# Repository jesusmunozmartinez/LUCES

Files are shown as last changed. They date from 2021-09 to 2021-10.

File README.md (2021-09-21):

# LUCES
## TFM LUCES Master SEEI
#### TITULACIÓN: Máster en Sistemas Electrónicos para Entornos Inteligentes
#### TÍTULO: "LUCES: Sistema inalámbrico de control de luminarias"
##### PALABRAS CLAVE: LUCES, ILUMINACIÓN, MESH, PCB, RED, SENSORES.
#### RESUMEN:
Este proyecto consiste en el desarrollo hardware, software y documentación de un sistema de control de iluminación inalámbrico. Este sistema permite integrar una luminaria convencional dentro de un sistema de control inteligente conectado a Internet. Su uso está orientado a la iluminación de espacios públicos como calles y parques. El control de encendido y de los niveles lumínicos de las luminarias integradas en el sistema, está basado en temporizaciones horarias, luminosidad ambiente o solar y presencia de usuarios en la vía iluminada. El sistema avisa por correo electrónico en caso de fallo de luminaria y proporciona información del consumo eléctrico, luminosidad ambiente, uso de la vía, etc. La arquitectura está basada en una red WiFi mallada con motas que controlan las luminarias y un nodo central que hace de puente con internet y proporciona el acceso a la gestión del sistema. La verificación de los requisitos se ha realizado sobre los prototipos funcionales desarrollados. Concluir que este sistema destaca por proporcionar la reducción del consumo eléctrico e inicia la posibilidad de integración de sistemas de iluminación en las “Ciudades inteligentes”. 

#### TITLE: “LIGHTS: Wireless luminaire control system”
##### KEYWORDS: LIGHTS, LIGHTING, MESH, PCB, NETWORK, SENSORS.
#### ABSTRACT:
This project consists of the development of hardware, software, and documentation of a wireless lighting control system. This system allows the integration of a conventional luminaire into an intelligent control system connected to the Internet. Its use is oriented to the lighting of public spaces such as streets and parks. The control of switching on and lighting levels of the luminaires integrated in the system is based on hourly timings, ambient or solar luminosity and the presence of users on the illuminated road. The system alerts by e-mail in case of luminaire failure and provides information on power consumption, ambient brightness, road use, etc. The architecture is based on a meshed WiFi network with motes that control the luminaires and a central node that bridges the Internet and provides access to system management. The verification of the requirements has been performed on the developed functional prototypes. To conclude that this system stands out for providing the reduction of electricity consumption and initiates the possibility of integration of lighting systems in "Smart Cities".

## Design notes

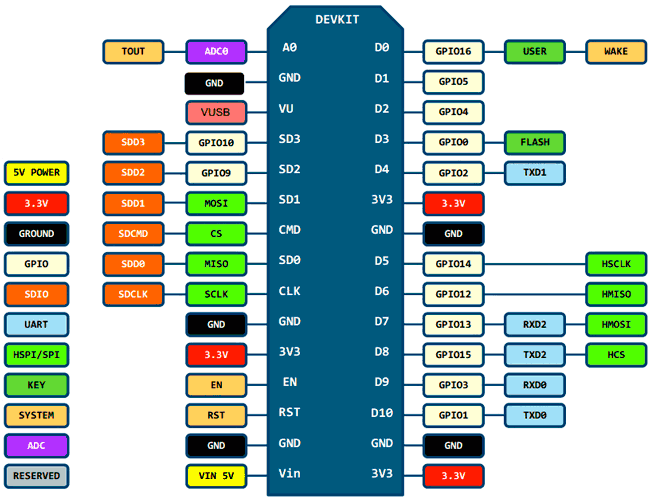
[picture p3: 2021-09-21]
Datasheet/esp8266-nodemcu-pinout-v3.png

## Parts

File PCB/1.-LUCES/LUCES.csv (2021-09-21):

Source: | C:\Users\kisum\Google Drive\UMA\MASTER_SEEI\16.-TFM\3.-Planos\kicad\LUCES\LUCES.sch
Date: | 01/08/2021 21:47:19
Tool: | Eeschema (5.1.10)-1
Component Count: | 5
Ref | Value | Footprint | Datasheet | Manufacturer | Vendor
J1 | Screw_Terminal_01x02 | TerminalBlock:TerminalBlock_Altech_AK300-2_P5.00mm | ~
PS1 | HLK-PM03 | Converter_ACDC:Converter_ACDC_HiLink_HLK-PMxx | http://www.hlktech.net/product_detail.php?ProId=59
R1 | 470 | Resistor_SMD:R_0805_2012Metric_Pad1.20x1.40mm_HandSolder | ~
SW1 | SW_Push | Button_Switch_SMD:SW_Push_1P1T_NO_6x6mm_H9.5mm | ~
U1 | ESP-12F | RF_Module:ESP-12E | http://wiki.ai-thinker.com/_media/esp8266/esp8266_series_modules_user_manual_v1.1.pdf

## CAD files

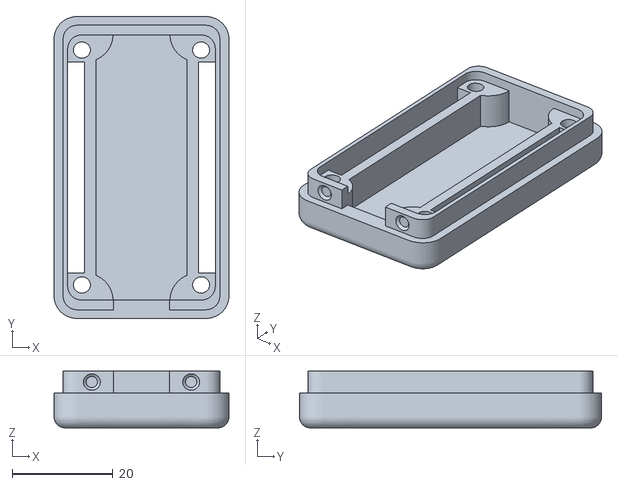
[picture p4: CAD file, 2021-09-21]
Carcasa3D/LucesNC-bottom.stl
34.8 x 60.1 x 11.3

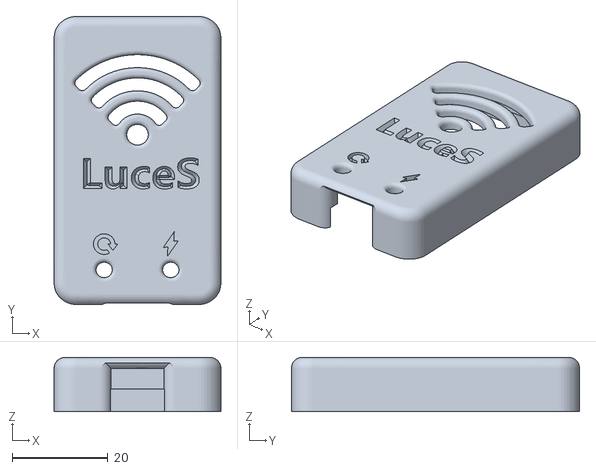
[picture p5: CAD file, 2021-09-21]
Carcasa3D/LucesNC-Top.stl
34.8 x 60.1 x 11.3

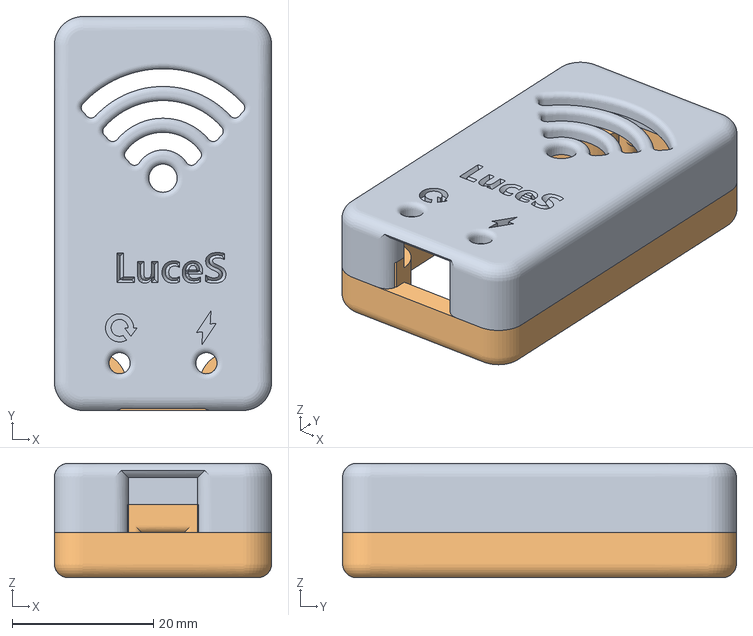
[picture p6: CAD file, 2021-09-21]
Carcasa3D/Luces.3mf
30.8 x 55.8 x 16.2 mm

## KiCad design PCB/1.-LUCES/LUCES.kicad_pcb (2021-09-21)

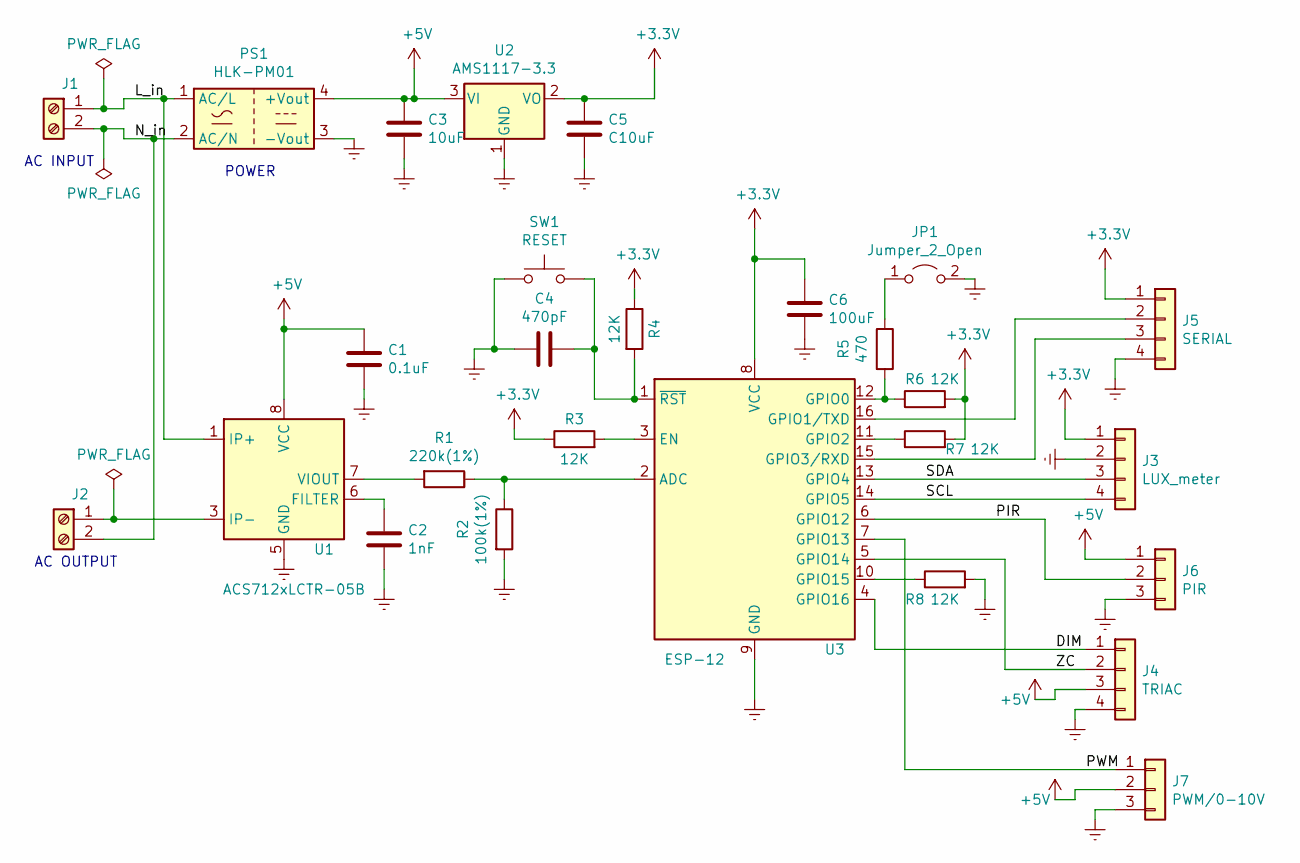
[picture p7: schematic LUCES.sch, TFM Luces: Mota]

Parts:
C1: 0.1uF; C_0805_2012Metric
C2: 1nF; C_0805_2012Metric
C3: 10uF; C_1206_3216Metric
C4: 470pF; C_0805_2012Metric
C5: C10uF; C_1206_3216Metric
C6: 100uF; C_0805_2012Metric
J1, J2: Screw_Terminal_01x02; TerminalBlock_Phoenix_MKDS-1,5-2_1x02_P5.00mm_Horizontal
J3: LUX_meter; JST_XH_S4B-XH-A-1_1x04_P2.50mm_Horizontal
J4: TRIAC; PinHeader_1x04_P2.54mm_Vertical
J5: SERIAL; PinHeader_1x04_P2.54mm_Vertical
J6: PIR; JST_XH_S3B-XH-A-1_1x03_P2.50mm_Horizontal
J7: PWM/0-10V; PinHeader_1x03_P2.54mm_Vertical
JP1: Jumper_2_Open; PinHeader_1x02_P2.54mm_Vertical
PS1: HLK-PM01; Converter_ACDC_HiLink_HLK-PMxx
R1: 220k(1%); R_0805_2012Metric_Pad1.20x1.40mm_HandSolder
R2: 100k(1%); R_0805_2012Metric_Pad1.20x1.40mm_HandSolder
R3, R4, R6, R7, R8: 12K; R_0805_2012Metric_Pad1.20x1.40mm_HandSolder
R5: 470; R_0805_2012Metric_Pad1.20x1.40mm_HandSolder
SW1: RESET; SW_SPST_PTS645
U1: ACS712xLCTR-05B; SOIC-8_3.9x4.9mm_P1.27mm
U2: AMS1117-3.3; SOT-223-3_TabPin2
U3: ESP-12

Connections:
+3V3: C5.1, C6.1, J3.1, J5.1, R3.1, R4.1, R6.2, R7.2, U2.2 (VO), U3.8 (VCC)
+5V: C1.1, C3.1, J4.3, J6.1, J7.2, PS1.4 (+Vout), U1.8 (VCC), U2.3 (VI)
/DIM: J4.1, U3.4 (GPIO16)
/L_in: J1.1, PS1.1 (AC/L), U1.1 (IP+), U1.2 (IP+)
/N_in: J1.2, J2.2, PS1.2 (AC/N)
/PIR: J6.2, U3.6 (GPIO12)
/PWM: J7.1, U3.7 (GPIO13)
/SCL: J3.4, U3.14 (GPIO5)
/SDA: J3.3, U3.13 (GPIO4)
/ZC: J4.2, U3.5 (GPIO14)
Earth: C1.2, C2.2, C3.2, C4.2, C5.2, C6.2, J3.2, J4.4, J5.4, J6.3, J7.3, JP1.2 (B), PS1.3 (-Vout), R2.2, R8.2, SW1.1, U1.5 (GND), U2.1 (GND), U3.9 (GND)
unnamed: C2.1, U1.6 (FILTER)
unnamed: C4.1, R4.2, SW1.2, U3.1 (~RST)
unnamed: J2.1, U1.3 (IP-), U1.4 (IP-)
unnamed: J5.2, U3.16 (GPIO1/TXD)
unnamed: J5.3, U3.15 (GPIO3/RXD)
unnamed: JP1.1 (A), R5.1
unnamed: R1.1, R2.1, U3.2 (ADC)
unnamed: R1.2, U1.7 (VIOUT)
unnamed: R3.2, U3.3 (EN)
unnamed: R5.2, R6.1, U3.12 (GPIO0)
unnamed: R7.1, U3.11 (GPIO2)
unnamed: R8.1, U3.10 (GPIO15)

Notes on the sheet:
POWER
AC INPUT
AC OUTPUT

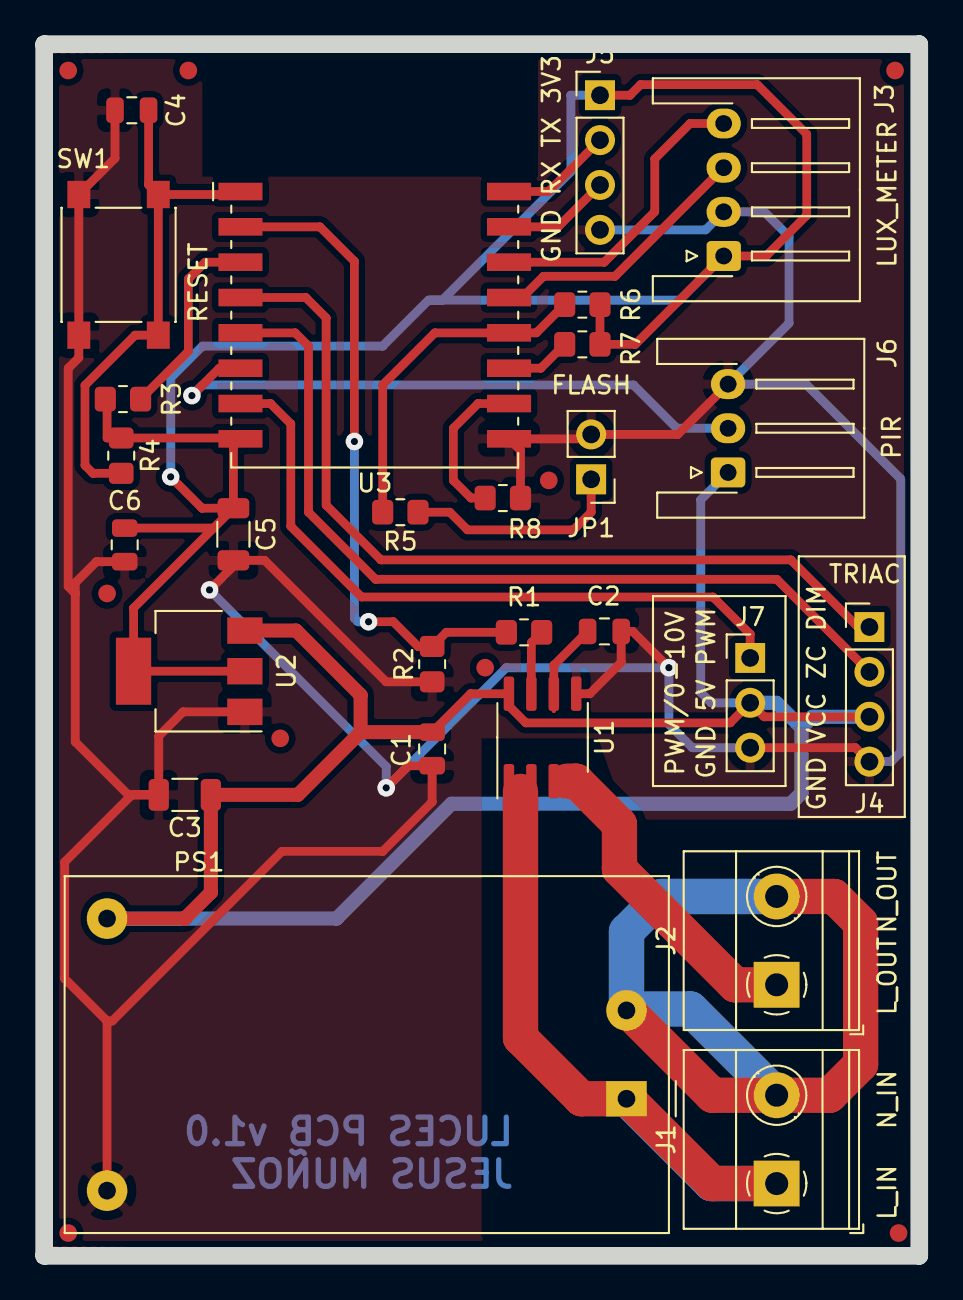
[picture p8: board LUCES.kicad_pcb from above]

Board: 2 copper layers, 49.5 x 68.6 mm, 27 parts (0 on the bottom side), 23 nets.

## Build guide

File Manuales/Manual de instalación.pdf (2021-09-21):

LUCES. Sistema inalámbrico de control de luminaria | Manual de instalación

# Manual de instalación V1.0

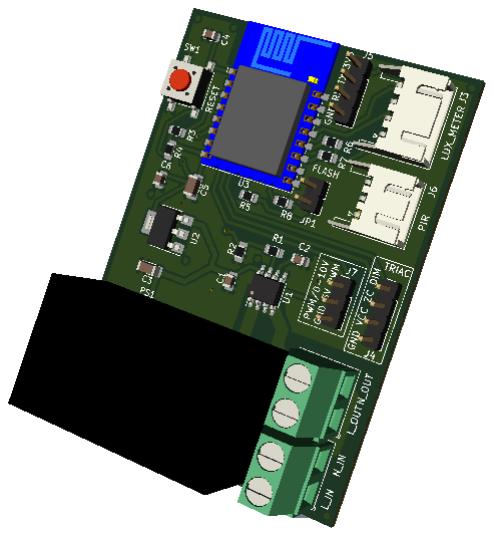
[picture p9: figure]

# Sistema inalámbrico de control de luminaria

# Especificaciones

Modelo | LUCES
Entrada | 100-240V AC 50/60Hz
Salida | 100-240V AC 50/60Hz 5A máxima
Carga máxima | 1200W/5A/
Wi-Fi | IEEE 802.11 b/g/n 2.4GHz
Sistemas operativos | Android/iOS/Windows/Linux/MacOS
Módulos de control de luminaria | 3 (uno por cada mota)
máximo número de motas | >50
Temperatura de funcionamiento | -10℃~40℃
Dimensiones | 70x50x34mm

# Introducción al producto

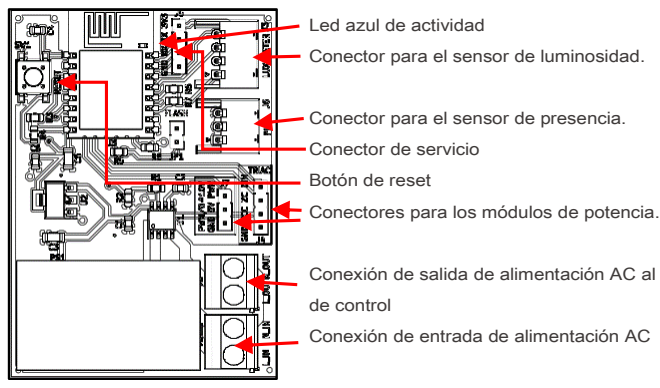
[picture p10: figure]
Led azul de actividad; Conector para el sensor de luminosidad.; Conector para el sensor de presencia.; Conector de servicio; Botón de reset; de control; Conexión de entrada de alimentación AC

Conectores para los módulos de potencia.

Conexión de salida de alimentación AC al módulo

¡Atención! Tenga cuidado de asegurarse que ha desconectado los cables de

alimentación AC antes de conectarlos.

# Características

Este sistema de control de luminaria está baso en un control integrado en un Nodo Central, accesible al usuario, y en un conjunto de motas inalámbricas instaladas por un profesional cualificado. Es por ello, que este manual, orientado al instalador, se centra en las motas inalámbricas.

Para una descripción del funcionamiento detallado del nodo central, consulte el manual del usuario.

El dispositivo es un controlador de luminarias inteligente mediante el protocolo Wi-Fi. Las motas inalámbricas integradas en las luminarias permiten un control de intensidad lumínica, detectar la luminosidad solar, consumo, presencia de personas, etc. , de tal forma que permite apagar o encender las luminarias de manera remota, programar el encendido o apagado en función de la luminosidad, solar o temporizado.

Control remoto

desde cualquier

plataforma

Programación
temporizada

Control
compartido

Monitoreo de
Alimentación

Estado de
sincronización

# Conexión de los sensores

Sensor de luminosidad.

El sensor de luminosidad se presenta con el siguiente aspecto, el color del soporte

puede diferir.

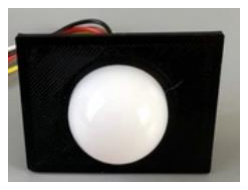
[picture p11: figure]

Elija una buena ubicación del sensor de luminosidad donde su medida no se vea afectada por la luz que emite la luminaria. Busque una zona de sombra de la luz de la luminaria como puede ser la parte superior o detrás del poste. La siguiente imagen muestra posibles ubicaciones recomendables.

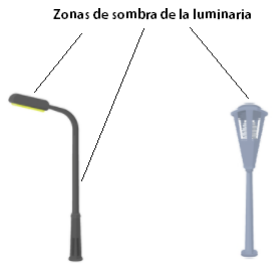
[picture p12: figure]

Una vez ubicado el sensor, conéctelo en el socket etiquetado como LUXMETER:

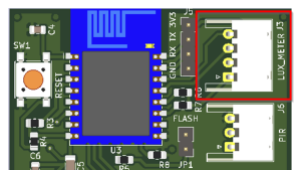
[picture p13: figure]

El sensor de luminosidad no necesita ningún tipo de ajuste ni calibración.

### Sensor de presencia de uso de la vía

El sensor de presencia de uso de la vía (PIR) se presenta con el siguiente aspecto, el

color del soporte puede diferir.

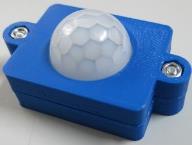
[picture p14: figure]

Antes de instalar él módulo puede ajustar los siguientes parámetros usando los potenciómetros que posee el módulo:

- Tiempo que permanece activo la señal de detección, desde 3 segundos hasta 5 minutos
- Distancia máxima de detección, desde 3 metras hasta 7 metros.

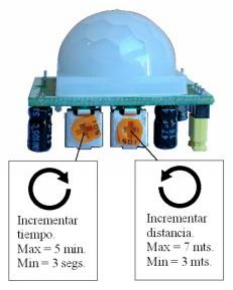
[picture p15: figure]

Elija una buena ubicación del sensor de presencia basándose que su rango de detección tiene un alcance de hasta 7 metros y ángulo de 110º. La siguiente imagen muestra posibles ubicaciones recomendables.

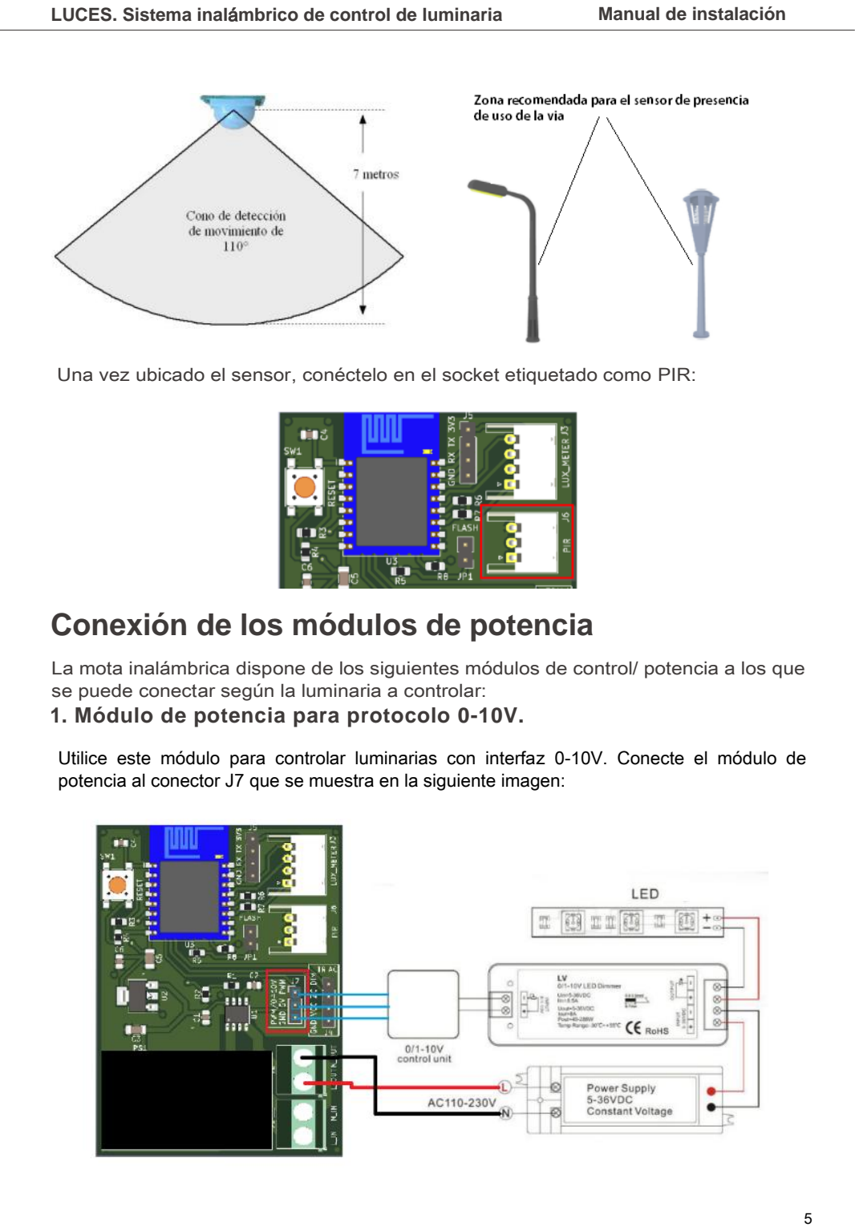
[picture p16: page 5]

Una vez ubicado el sensor, conéctelo en el socket etiquetado como PIR:

# Conexión de los módulos de potencia

La mota inalámbrica dispone de los siguientes módulos de control/ potencia a los que se puede conectar según la luminaria a controlar:
1. Módulo de potencia para protocolo 0-10V.

Utilice este módulo para controlar luminarias con interfaz 0-10V. Conecte el módulo de potencia al conector J7 que se muestra en la siguiente imagen:

2. Módulo de potencia para tensiones DC.

Utilice este módulo para controlar luminarias basadas en regulación de intensidad por ajuste de la tensión DC. Conecte el módulo de potencia al conector J7 que se muestra en la siguiente imagen:

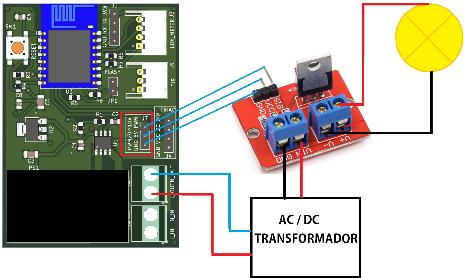
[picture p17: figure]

3. Módulo de potencia para corriente DC.

Utilice este módulo para controlar luminarias basadas en regulación de la intensidad por limitación de la corriente DC. Conecte el módulo de potencia al conector J7 que se muestra en la siguiente imagen:

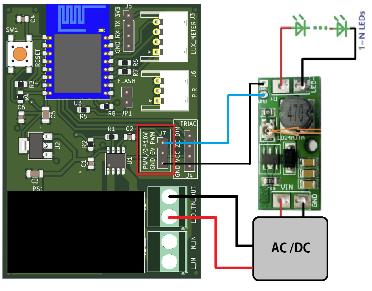
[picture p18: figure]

4. Módulo de potencia para tensiones AC.

Utilice este módulo para controlar luminarias que funcionen con corriente AC (100-240V) y tengan capacidad de regulación de luminosidad como las bombillas incandescentes. Las bombillas LED deben ser regulables, en caso contrario apreciará un parpadeo en las mismas. Conecte el módulo de potencia al conector J4.

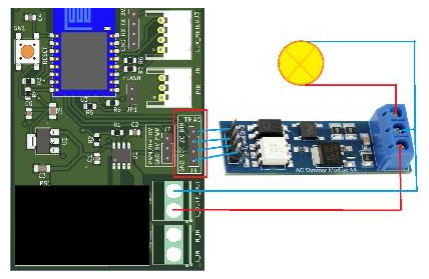
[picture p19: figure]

# Conexión de la alimentación AC

Una Realice la conexión de la alimentación AC siguiendo el siguiente esquema:

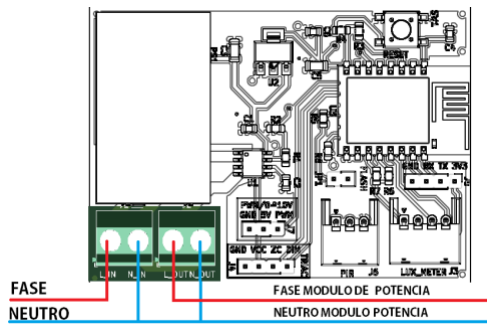
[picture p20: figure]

# Puesta en marcha

Revise que ha realizado todas las conexiones que a continuación se detallan:

1. Sensor de luminosidad ambiente y de presencia
2. Módulo de potencia, cableado de control y de alimentación
3. Alimentación AC de la mota inalámbrica.

Si todo está correctamente conectado puede alimentar la Mota inalámbrica, el led azul mostrará actividad y se conectará al nodo central.

Led azul de actividad

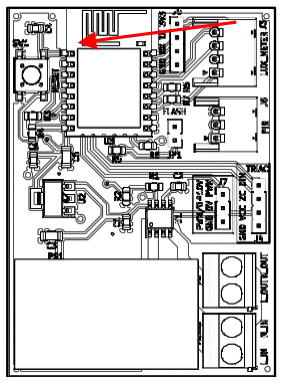
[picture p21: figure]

Si necesitas configurar el nodo central, presiona sin soltar el botón de acceso al modo configuración, luego el dispositivo entra en el modo de configuración donde podrás configurarlo conectándose al punto de acceso creado.

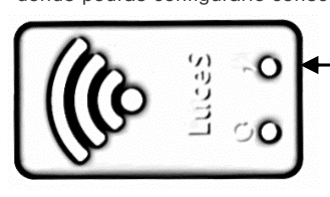
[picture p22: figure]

Botón de acceso al Modo de configuración

# Problemas frecuentes

P: ¿Por qué el dispositivo no se conecta a la red Wi-Fi MESH de mi instalación?
R: El dispositivo recién añadido necesita hasta 1 a 2 minutos para conectarse a la red Wi-Fi MESH. Si permanece sin conexión durante mucho tiempo, pulse el botón de reset. Si no ha solucionado el problema verifique los siguientes puntos

① Es posible que el Nodo central esté apagado. Verifique su funcionamiento

② Es posible que el dispositivo no tenga alimentación AC. Verifique si hay actividad en

el led azul.
③ Revise las conexiones con el módulo de potencia instalado.

P: ¿Por qué el dispositivo no detecta la presencia de usuarios en la vía correctamente”? R: El dispositivo de detección de personas (PIR) debe calibrarse correctamente según la zona a controlar, revise la sección “conexión de los sensores” para más información. Si no ha solucionado el problema verifique los siguientes puntos

① Es posible que el dispositivo de detección PIR no tenga alimentación. Verifique si

hay actividad en el del mismo.
② Revise las conexiones y el cableado con el módulo PIR.

P: ¿Por qué el dispositivo no detecta correctamente la luminosidad ambiente?
R: El dispositivo de detección de personas (PIR) debe calibrarse correctamente según la zona a controlar, revise la sección “conexión de los sensores” para más información. Si no ha solucionado el problema verifique los siguientes puntos

① Es posible que el dispositivo de detección PIR no tenga alimentación. Verifique si

hay actividad en el del mismo.
② Revise las conexiones y el cableado con el módulo PIR.

# FCC Warning

Changes or modifications not expressly approved by the party responsible for compliance could avoid the user’s authority to operate the equipment.
This device complies with part 15 of the FCC Rules. Operation is subject to the following two conditions: (1) This device may not cause harmful interference, and (2) this device must accept any interference received, including interference that may cause undesired operation.

FCC Radiation Exposure Statement:

This equipment complies with FCC radiation exposure limits set forth for an uncontrolled environment. This equipment should be installed and operated with minimum distance20cm between the radiator & your body. This transmitter must not be co-located or operating in conjunction with any other antenna or transmitter.

Note:

This equipment has been tested and found to comply with the limits for a Class B digital device, pursuant to part 15 of the FCC Rules. These limits are designed to provide reasonable protection against harmful interference in a residential installation. This equipment generates, uses and can radiate radio frequency energy and, if not installed and used in accordance with the instructions, may cause harmful interference to radio communications. However, there is no guarantee that interference will not occur in a particular installation. If this equipment does cause harmful interference to radio or television reception, which can be determined by turning the equipment off and on, the user is encouraged to try to correct the interference by one or more of the following measures:

— Reorient or relocate the receiving antenna.
— Increase the separation between the equipment and receiver.
— Connect the equipment into an outlet on a circuit different from that to which the receiver is connected.
— Consult the dealer or an experienced radio/TV technician for help.

# For FCC:

Frequency range
Wi-Fi: 2412-2462MHz | BT: 2402-2480MHz
Maximum RF output power of the product
Wi-Fi: 17.85dBm | BT: -1.90dBm

# For CE RED:

Frequency range
Wi-Fi: 2412-2472MHz | BT: 2402-2480MHz

Maximum RF output power of the product

Wi-Fi: 18.36dBm | BT: 3.93dBm (Inclusion antenna gain)

# RF exposure

RF exposure information: The Maximum Permissible Exposure ( MPE) level is calculated based on a distance of d=20 cm between the device and the human body. To maintain compliance with the RF exposure requirement, a separation distance of 20 cm between the device and the human should be maintained.

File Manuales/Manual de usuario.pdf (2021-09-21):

LUCES. Sistema inalámbrico de control de luminaria | Manual de usuario

# Manual de usuario V1.0

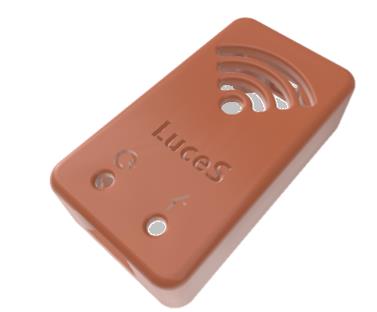
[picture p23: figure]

# Sistema inalámbrico de control de luminaria

# Especificaciones

Modelo | LUCES
Entrada | 100-240V AC 50/60Hz
Salida | 100-240V AC 50/60Hz 5A máxima
Carga máxima | 1200W/5A/
Wi-Fi | IEEE 802.11 b/g/n 2.4GHz
Sistemas operativos | Android/iOS/Windows/Linux/MacOS
Módulos de control de luminaria | 3 (uno por cada mota)
máximo número de motas | >50
Temperatura de funcionamiento | -10℃~40℃
Dimensiones | 70x50x34mm

# Introducción al producto

Botón de acceso al Modo de configuración

Botón de reset

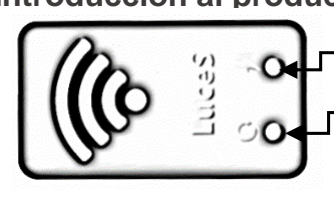
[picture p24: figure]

Nodo central

Para el nodo central se recomienda usar el adaptador de corriente de 1A suministrado.

# Características

Este sistema de control de luminaria está baso en un control integrado en un Nodo Central, accesible al usuario, y en un conjunto de motas inalámbricas instaladas por un profesional cualificado. Es por ello, que este manual, orientado al usuario, se centra en el uso del Nodo Central.

Para descripción del funcionamiento detallado de las motas inalámbricas, consulte el manual de instalación.

El dispositivo es un controlador de luminarias inteligente mediante el protocolo Wi-Fi. Las motas inalámbricas integradas en las luminarias permiten un control de intensidad lumínica, detectar la luminosidad solar, consumo, presencia de personas, etc. , de tal forma que permite apagar o encender las luminarias de manera remota, programar el encendido o apagado en función de la luminosidad, solar o temporizado.

Control remoto

desde cualquier

plataforma

Programación
temporizada

Control
compartido

Monitoreo de
Alimentación

Estado de
sincronización

# Primer encendido

Después de encender el nodo central por primera vez, el dispositivo se pondrá en modo de configuración durante el primer uso.

Si el dispositivo no entra en modo de configuración, podrá acceder a dicho modo mediante el botón de acceso en el panel de control o mediante la pulsación del botón Modo de configuración durante un segundo. A continuación, suelte el botón.

# Modo de configuración

Después de encender el nodo central por primera vez, el dispositivo se pondrá en modo de configuración durante el primer uso.

Para acceder al dispositivo, conéctese a la red WiFi con el nombre LUCES_CONFIG.

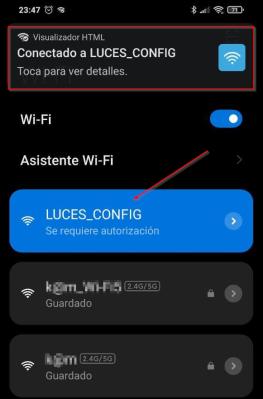
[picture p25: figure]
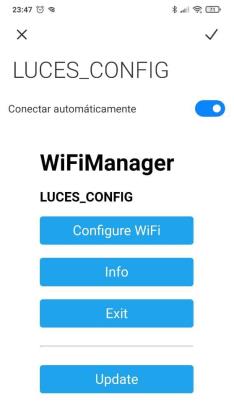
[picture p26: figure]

Una vez conectado a la red LUCES_CONFIG, podrá acceder directamente al panel de configuración abriendo su navegador o pulsando en su teléfono en “Toca para ver detalles”.
En caso de que esto no ocurra puede acceder manualmente en la dirección http://192.168.4.1.

### Añadir red local

Una vez dentro del panel de configuración, puse sobre el botón “Configure WiFi” para iniciar el escaneo de redes inalámbricas . Tras unos instantes aparecerá el listado con las redes encontradas.

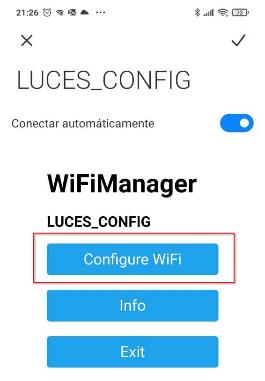
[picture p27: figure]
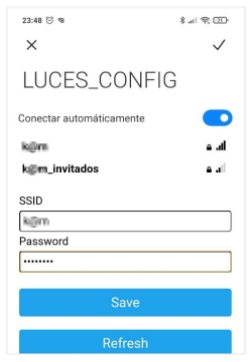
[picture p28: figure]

Seleccione la red, introduzca la contraseña de acceso y el Nodo Central se conectará a la red indicada con asignación dinámica de dirección IP. Realice una búsqueda en su red con el hostname “LUCES” o verifique en la tabla DHCP de su router la dirección IP asignada.

Recomendamos configurar una IP fija en su router para mayor comodidad. Consulte a su administrador de red para más información.

# Panel de control

Una vez conectado el Nodo Central a su red local con salida a internet, se sincronizará automáticamente la hora del sistema LUCES. Acceda al panel de control donde podrá realizar las siguientes funciones:
1. Información de la red de motas inalámbricas.

En el panel de control se muestran en tiempo real la información de las motas conectadas, su estado, las medidas de sus sensores y si se ha detectado fallo en la luminaria.

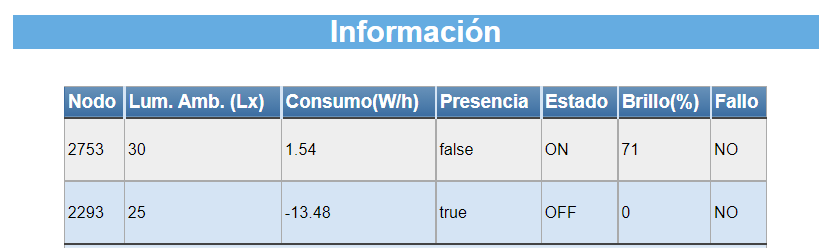
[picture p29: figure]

### 2. Configuración y control

Aquí podrá configurar el sistema de iluminación entre sus tres modos de encendido y sus tres modos de ajuste de intensidad lumínica. El ajuste de intensidad lumínica por detección de presencia está activado por defecto en todas las configuraciones, para intentar maximizar el ahorro de energía.

Modo Manual:

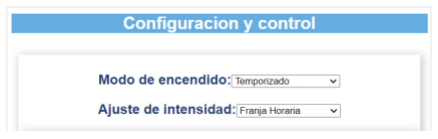
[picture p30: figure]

Este modo permite encender y apagar las luminarias en cualquier momento. Permite ajustar la intensidad lumínica y también la intensidad cuando no se detecten personas en las zonas donde se han instalado las luminarias.

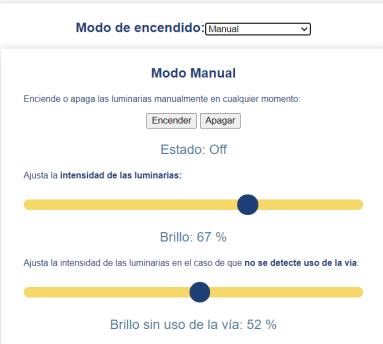
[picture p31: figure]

Modo de encendido por luminosidad ambiente:
Este modo permite encender y apagar las luminarias según el nivel lumínico configurado. Las luminarias se encenderán cuando el nivel de luminosidad medido se inferior al valor ajustado. Las luminarias se apagarán cuando el nivel lumínico se superior al ajustado.

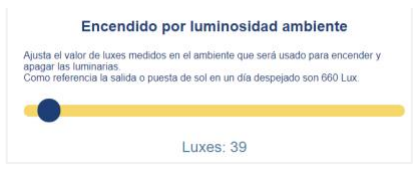
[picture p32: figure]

Luego, este modo dispone permite configurar manualmente la intensidad lumínica o mediante una selección por franja horaria, pensado para poner diferentes ajustes de luminosidad para el anochecer, noche y amanecer.

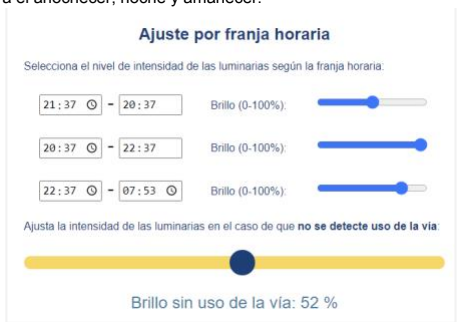
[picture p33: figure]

Modo de encendido temporizado:
En este modo el encendido y el apagado se realiza según las horas programadas. Los modos de ajuste de intensidad lumínica disponibles en este modo son todos los disponibles, así que podremos configurarlo tanto manualmente como por franja horaria y siempre con el modo de detección de uso de la vía funcionando.

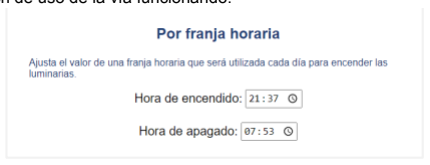
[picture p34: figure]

### 3. Añadir cuenta de correo de mantenimiento

El sistema permite configurar una cuenta de correo donde se avisará en caso de fallo de luminaria.

### 4. Registro del sistema

En esta sección podrá visualizar los eventos y mensajes registrados en el sistema de control Luces. Podrá descargar el fichero así borrarlo y /o recargar el visualizador para ver los últimos eventos registrados.

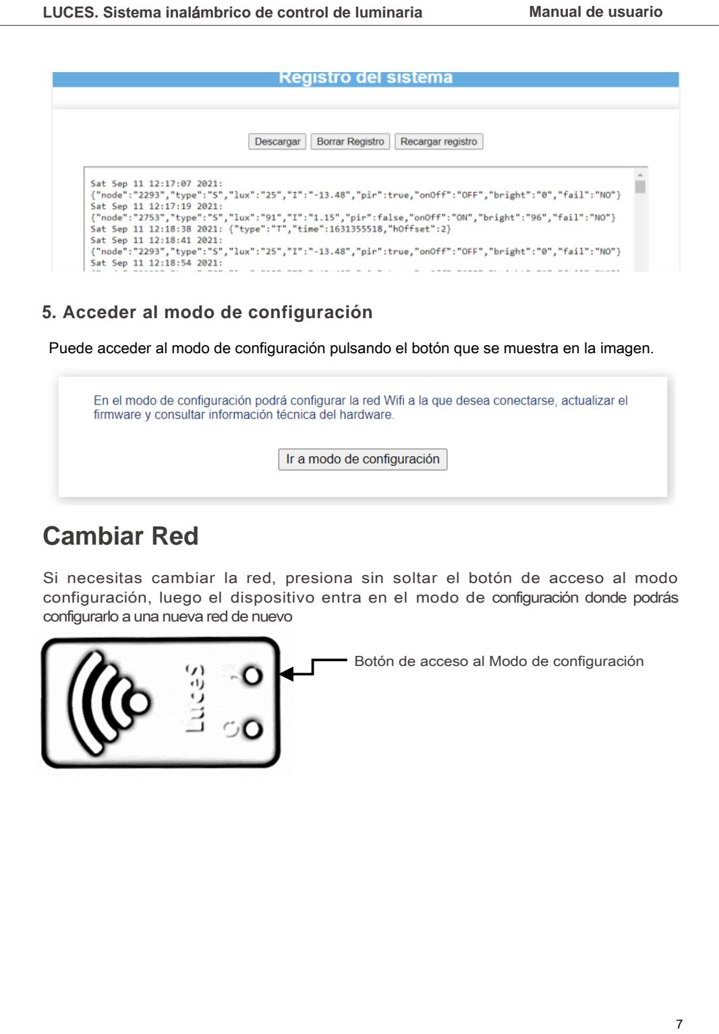
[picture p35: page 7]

### 5. Acceder al modo de configuración

Puede acceder al modo de configuración pulsando el botón que se muestra en la imagen.

# Cambiar Red

Si necesitas cambiar la red, presiona sin soltar el botón de acceso al modo configuración, luego el dispositivo entra en el modo de configuración donde podrás configurarlo a una nueva red de nuevo

Botón de acceso al Modo de configuración

# Problemas frecuentes

P: ¿Por qué el dispositivo no se conecta a la red Wi-Fi de mi instalación”?
R: El dispositivo recién añadido necesita de 1 a 2 minutos para conectarse a Wi-Fi y a la red. Si permanece sin conexión durante mucho tiempo, evalúe la situación analizando los siguientes puntos.

① Es posible que haya introducido una contraseña de Wi-Fi incorrecta.
② Es posible que la distancia entre el interruptor y el router sea demasiado grande o que el entorno provoque interferencias. Piense en acercarlos entre sí.
Si falla, vuelva a añadirlo.
③ La red 5G Wi-Fi no es compatible y solo admite la red inalámbrica de 2,4 GHz.
④ Es posible que el filtrado de direcciones MAC esté activado. Desactívelo.

Si no ha sido posible solucionar el problema mediante ninguno de los métodos anteriores, puede abrir la red de datos móviles del teléfono para crear un punto de acceso Wi-Fi y, a continuación, volver a añadir el dispositivo.

# FCC Warning

Changes or modifications not expressly approved by the party responsible for compliance could avoid the user’s authority to operate the equipment.
This device complies with part 15 of the FCC Rules. Operation is subject to the following two conditions: (1) This device may not cause harmful interference, and (2) this device must accept any interference received, including interference that may cause undesired operation.

FCC Radiation Exposure Statement:

This equipment complies with FCC radiation exposure limits set forth for an uncontrolled environment. This equipment should be installed and operated with minimum distance20cm between the radiator & your body. This transmitter must not be co-located or operating in conjunction with any other antenna or transmitter.

Note:

This equipment has been tested and found to comply with the limits for a Class B digital device, pursuant to part 15 of the FCC Rules. These limits are designed to provide reasonable protection against harmful interference in a residential installation. This equipment generates, uses and can radiate radio frequency energy and, if not installed and used in accordance with the instructions, may cause harmful interference to radio communications. However, there is no guarantee that interference will not occur in a particular installation. If this equipment does cause harmful interference to radio or television reception, which can be determined by turning the equipment off and on, the user is encouraged to try to correct the interference by one or more of the following measures:

— Reorient or relocate the receiving antenna.
— Increase the separation between the equipment and receiver.
— Connect the equipment into an outlet on a circuit different from that to which the receiver is connected.
— Consult the dealer or an experienced radio/TV technician for help.

# For FCC:

Frequency range
Wi-Fi: 2412-2462MHz | BT: 2402-2480MHz
Maximum RF output power of the product
Wi-Fi: 17.85dBm | BT: -1.90dBm

# For CE RED:

Frequency range
Wi-Fi: 2412-2472MHz | BT: 2402-2480MHz

Maximum RF output power of the product

Wi-Fi: 18.36dBm | BT: 3.93dBm (Inclusion antenna gain)

# RF exposure

RF exposure information: The Maximum Permissible Exposure ( MPE) level is calculated based on a distance of d=20 cm between the device and the human body. To maintain compliance with the RF exposure requirement, a separation distance of 20 cm between the device and the human should be maintained.

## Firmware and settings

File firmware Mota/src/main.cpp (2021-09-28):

//************************************************************
// Author: Jesús Muñoz Martínez
// Proyect: LUCES.
// Trabajo Fin de Master. 
// Master de Sistemas Electrónicos para Entornos Inteligentes
//
// 1. blinks led once for every node on the mesh
// 2. blink cycle repeats every BLINK_PERIOD
// 3. sends a silly message to every node on the mesh at a random time between 1 and 5 seconds
// 4. prints anything it receives to Serial.print
// 5. OTA support and can be updated remotely
// 6. Support for BH1750 luminosity sensor  
// 7. Support for PIR sensor
// 8. Support for ACS712T
// 9. LittleFS for save configuration file
// 10. Control LED driver with PWM signal (0-10 by hardware)
// 11. Task fading
//************************************************************

#include "painlessMesh.h"
#include <Arduino_JSON.h>
#include <wire.h>

#include "config.h"                 //configuration file
#include "mesh.h"
#include "readSensors.h"
#include "configFile.h"
#include "controlLum.h"
#include "utils.h"


JSONVar       config;
Scheduler     userScheduler; // to control task
painlessMesh  mesh;


bool onStatus = false;
bool onPresence = false;
int bright = 0;    // bright level [0..100].
int brightNow = 0;    
int luxes = 0;


// Task Handlers, constructor

Task taskSendStatus( TASK_SECOND * 1, TASK_FOREVER, &sendMessageStatus );  //start with 5 second interval
Task taskControlLum( TASK_SECOND * 1, TASK_FOREVER, &controlLum );  //start with 1 second interval
Task taskBlinkNoNodes;
Task taskFadeLum( TASK_SECOND * 0.02, TASK_FOREVER, &fadeLum );  

bool onFlag = false;


//  ----------------- SETUP -------------------------------- 

void setup() {

  pinMode(LED, OUTPUT);
  pinMode(PIRpin, INPUT);
  pinMode(A0, INPUT);
  pinMode(PWM, OUTPUT);
  pinMode(ZC, INPUT);
  pinMode(TRIAC, OUTPUT);
  analogWriteRange(100);
  Serial.begin(115200);
  printFwVersion();
  initFS();
  Wire.begin();  //I2C BUS

  initBH1750();
  loadConfig();
  initMesh();

   
  // Task blink Nodes
  taskBlinkNoNodes.set(BLINK_PERIOD, (mesh.getNodeList().size() + 1) * 2, []() {
      // If on, switch off, else switch on
      if (onFlag)
        onFlag = false;
      else
        onFlag = true;
      taskBlinkNoNodes.delay(BLINK_DURATION);

      if (taskBlinkNoNodes.isLastIteration()) {
        // Finished blinking. Reset task for next run 
        // blink number of nodes (including this node) times
        taskBlinkNoNodes.setIterations((mesh.getNodeList().size() + 1) * 2);
        // Calculate delay based on current mesh time and BLINK_PERIOD
        // This results in blinks between nodes being synced
        taskBlinkNoNodes.enableDelayed(BLINK_PERIOD - 
            (mesh.getNodeTime() % (BLINK_PERIOD*1000))/1000);
      }
  });

  userScheduler.addTask(taskBlinkNoNodes);
  taskBlinkNoNodes.enable();

  // Task Send Status 
  userScheduler.addTask(taskSendStatus);
  taskSendStatus.enable();

  // Task Control luminosity 
  userScheduler.addTask(taskControlLum);
  taskControlLum.enable();

    // Task Control luminosity 
  userScheduler.addTask(taskFadeLum);
  //taskFadeLum.enable();
 
  randomSeed(analogRead(A0));
}

//   -------------- Loop ----------------------- 
void loop() {  
  updateMesh();
  digitalWrite(LED, !onFlag);
}

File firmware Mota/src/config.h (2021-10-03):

//************************************************************
// Author: Jesús Muñoz Martínez
// Proyect: Trabajo Fin de Master: LUCES.
// Master de Sistemas Electrónicos para Entornos Inteligentes
// Root Node.
// Description: Configuration file
//
//************************************************************



#ifndef CONFIG_H
#define CONFIG_H

#include <Arduino_JSON.h>

const   String verFw = "Luces_ESP8266_mota_260921.bin";

// MESH configuration
#define   MESH_SSID       "LucesMesh"
#define   MESH_PASSWORD   "Password1"
#define   MESH_PORT       5555


#define    LED             2       // GPIO number of connected LED, ON ESP-12 IS GPIO2
#define    BLINK_PERIOD    3000    // milliseconds until cycle repeat
#define    BLINK_DURATION  100     // milliseconds LED is on for
#define    PIRpin          12       // GPIO number of connected PIR SENSOR

#define    PWM             13       // GPIO number of connected PWM, 1.-10v CONTROL
#define    TRIAC           15       // GPIO for TRIAC control
#define    ZC              D5       // GPIO for Zero cross interruption

#endif // END CONFIG_H

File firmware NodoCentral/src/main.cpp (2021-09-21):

//************************************************************
// Author: Jesús Muñoz Martínez
// Project: LUCES.
// Trabajo Fin de Master. 
// Master de Sistemas Electrónicos para Entornos Inteligentes
// Root node running in ESP32 device.
//  - OTA support 
//  - Web Server with panel control
//  - NTP service to sync internet time
//  - System Log
//  - Save / restore Config File
//  - bridge backhaul <-> Mesh network
//  - send an email with error message
//
//************************************************************

#include <Arduino.h>
#include "IPAddress.h"
#include <painlessMesh.h>

#include "config.h"        // system configuration file
#include "logSystem.h"
#include "webServerCP.h"
#include "utils.h"
#include "mesh.h"
#include "initSetup.h"
#include "configFile.h"



bool configMode = true;

Scheduler  userScheduler; // to control tasks

// Task Handlers, constructor

Task taskNTPSync( TASK_SECOND * 3, TASK_FOREVER, &ntpSync ); // utils.cpp
Task taskWsCleanup( TASK_SECOND * 1, TASK_FOREVER, &wsCleanupClients ); 
Task taskCheckBHIP(TASK_SECOND * 1, TASK_FOREVER, &checkBHIP);
Task taskGotoConfig(TASK_SECOND * 1, TASK_FOREVER, &gotoConfigMode);


//-------- ISR -----------------
void IRAM_ATTR isr() {
  Serial.println("ISR");
  taskGotoConfig.enable();
}

// ------------------- SETUP ------------------------
void setup() {
  Serial.begin(115200);
  printFwVersion();
  initFS();
  configMode = isConfigMode();
  if (configMode){
      configModeStart();
  }else{
    pinMode(0, INPUT_PULLUP);
    attachInterrupt(0, isr, FALLING);
    initMesh();
    initWebServer();
    initLog();  

    //--- Task NTP syncronize --
    userScheduler.addTask( taskNTPSync );
    
    //--- Task websocket clean clients --
    userScheduler.addTask( taskWsCleanup );
    taskWsCleanup.enable();

      //--- Task check backhaulIP --
    userScheduler.addTask( taskCheckBHIP );
    taskCheckBHIP.enable();

    //--- Task go to config modeP --
    userScheduler.addTask( taskGotoConfig );

    randomSeed(analogRead(A0));
  }
}

// -------------- Loop ---------------------------

void loop() {
  if (!configMode){
      updateMesh();
  }  
}

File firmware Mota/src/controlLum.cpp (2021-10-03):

//************************************************************
// Author: Jesús Muñoz Martínez
// Proyect: Trabajo Fin de Master: LUCES.
// Master de Sistemas Electrónicos para Entornos Inteligentes
// Mota Node.
// Description: Header file from controlLum.cpp
//
//************************************************************


/* Example message
msg={"type":"C","mode":"lumAmb","mOn":"Off","mLux":"39","mTon":"19:54","mToff":"06:53","lum":"time",
"bVal":"67","bT1":"20:37","bT2":"22:37","bT1Lux":"50","bT2Lux":"100","bT3Lux":"80","bPre":"52"}
*/


#include "controlLum.h"
#include "utils.h"
#include <TimeLib.h>


extern JSONVar config;
extern bool onPresence;
extern bool onStatus;
extern int bright;    // bright level [0..255] for getreadings
extern int brightNow; 
extern int luxes;
extern Task taskFadeLum;



void fadeLum(){
    if (bright > brightNow){
        brightNow++;
        //int value = map(brightNow, 0, 100, 0, 255);
        analogWrite(PWM, brightNow);
    }else if (bright < brightNow){
        brightNow--;
        //int value = map(brightNow, 0, 100, 0, 255);
        analogWrite(PWM, brightNow);
    }
}


void powerLum(){
    int value;
    if (!onPresence){
        value = atoi(config["bPre"]);
        bright = value;
    }else{ 
        if((strcmp(config["lum"],"time") == 0)){
            value = bright;
        }else{
            value = atoi(config["bVal"]);
            bright = value;
        }
    }
    if (bright == brightNow){
        taskFadeLum.disable();
    }else{
        taskFadeLum.enable();
    }
}



void parseTime(String str, int &hour, int &min  ){

    JSONVar jTime = config[str];
    String jTimeStr = JSON.stringify(jTime);
    hour = jTimeStr.substring(1,3).toInt();
    min = jTimeStr.substring(4,6).toInt();
}



bool timeOnRange(String str1, String str2){
    time_t tnow = now();
    int hnow= hour(tnow); 
    int mnow= minute(tnow);
    int hon, mon, hoff, moff; 
    parseTime(str1, hon, mon);  
    parseTime(str2, hoff, moff);  

    if (hon > hoff){ // time off is in the next day
        if (hnow > hon && hnow<=23){    
            return true;   
        }else if(hnow < hoff){
            return true;       
        }else if (hnow == hon && mnow >= mon){
            return true;
        }else if (hnow == hoff&&mnow <= moff){
            return true;
        }else{
            return false;
        }   
    }else{  // time off in the same day
        if (hnow > hon && hnow<hoff){
            return true;
        }else if (hnow == hon && mnow >= mon){
            return true;
        }else if (hnow == hoff&&mnow <= moff){
            return true;
        }else{
            return false;
        }
    }
}




void checkTimeRange(){
    if (timeOnRange("mTon","bT1")){
        bright = atoi(config["bT1Lux"]);
        //Serial.println("range1");
    }else if (timeOnRange("bT1","bT2")){
        bright = atoi(config["bT2Lux"]);
        //Serial.println("range2");
    }else if (timeOnRange("bT2","mToff")){
        bright = atoi(config["bT3Lux"]);
        //Serial.println("range3");
    } 
}



void controlLum(){
    if (strcmp(config["mode"], "manual") == 0) {
        //Serial.println("Modo manual");
        if (strcmp(config["mOn"], "on") == 0) {
            powerLum();
            onStatus = true;
        }else if (strcmp(config["mOn"], "off") == 0) {
            analogWrite(PWM, 0);
            onStatus = false;
            bright = 0;
            brightNow = 0;
        }
    }else if (strcmp(config["mode"], "lumAmb") == 0){
        int luxOnOff = atoi(config["mLux"]);
        if (luxes < luxOnOff){
            onStatus = true;
            if(strcmp(config["lum"], "manual") == 0){
               // Serial.println("Modo LumAmb, manual on");
                powerLum();
            }else{
               // Serial.println("Modo LumAmb, time");
                checkTimeRange();
                powerLum();
            }
        }else{
           // Serial.println("Modo LumAmb, off");
            analogWrite(PWM, 0);
            onStatus = false;
            bright = 0;
            brightNow = 0;
        }
    }else if (strcmp(config["mode"], "time") == 0){
          if (timeOnRange("mTon","mToff")){  
            onStatus = true;
            if(strcmp(config["lum"], "manual") == 0){
               // Serial.println("Modo Time, manual on");
                powerLum();
            }else{
               // Serial.println("Modo Time, time on");
                checkTimeRange();
                powerLum();
            }
        }else{
            //Serial.println("Modo Time, off");
            analogWrite(PWM, 0);
            onStatus = false;
            bright = 0;
            brightNow = 0;
        }
    }
}
